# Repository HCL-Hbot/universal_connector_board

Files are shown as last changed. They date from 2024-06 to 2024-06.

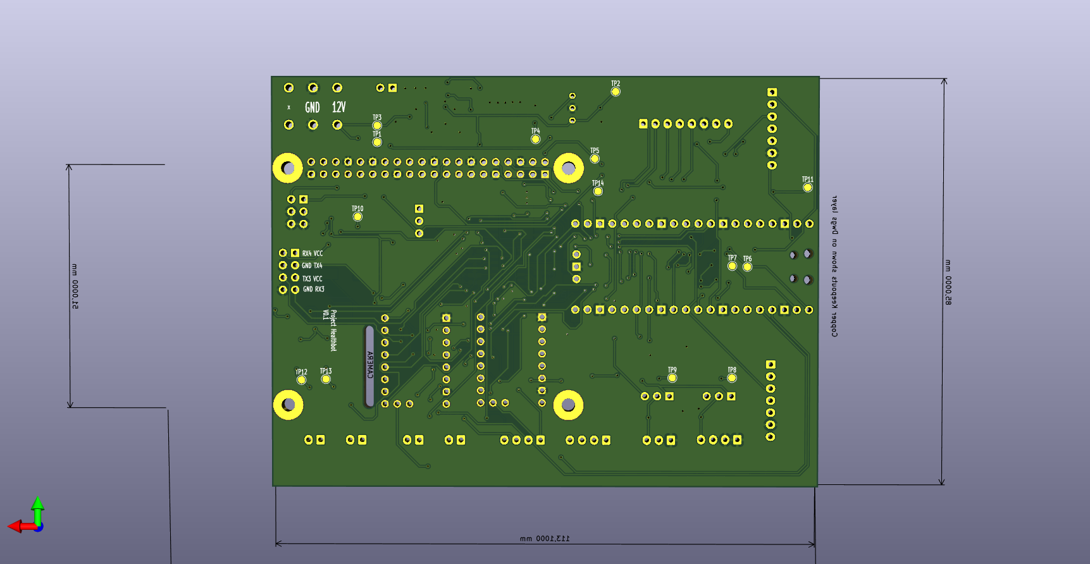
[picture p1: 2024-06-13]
Media/Back_3D.png

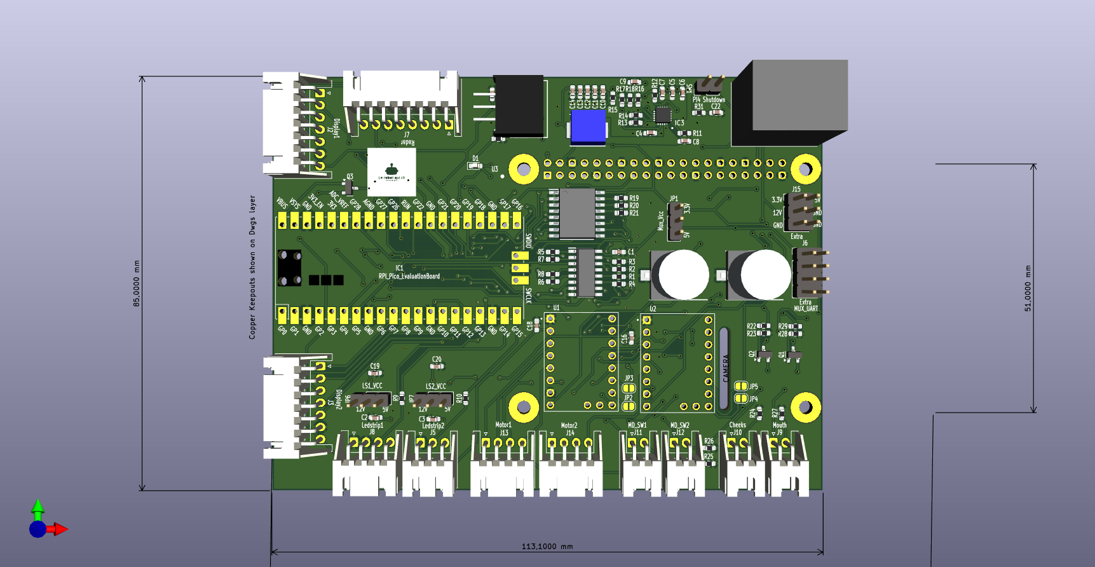
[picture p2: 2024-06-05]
Media/Front_3D.png

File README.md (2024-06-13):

# Healthboth PCB Design
This document outlines the contribution to a PCB design for project Healthbot, which is part of the Health Concept Lab of HAN University of Applied Sciences. It is part of a semester 6 student project including 3 Embedded Systems Engineers and 4 Industrial Design Engineers. The goal for this project was developing a social robot for healthcare, with several functionalities. This PCB is made to be integrated in the robot, but also made quite universal, so it can be used in new robot designs. In the folder media, there are images of the PCB. Because this was a first version, please look at the recommendations below!

## Components
Some components on the PCB that were needed are the I/O Expander, voltage regulators and an UART multiplexer. 
  ### I/O Expander
  Because the GPIO pins of the Pico were completely full and we still needed some, we added an I/O Expander which works with I2C. This expander has 8 I/O channels,   which are also all connected. 
  ### Voltage regulators
  Because of the several needed voltages for the components, two regulators are on the PCB. There is 12 Volt coming in to the PCB via the block terminal. This is     guided to a TSR 1-2433, which converts it to 3.3V. Also a 5V regulator is on the PCB, which was more complicated because it has to have a high output current due   to the ledstrips needing lots of current. 
  ### UART Multiplexer
  The motor driver modules can be controlled via UART communication. Because the Pico doesn't have lots of UART channels, and are already needed for                  communication between the RPI4 and the Pico e.g., an UART Multiplexer was added. Although we don't use it to control our motor drivers, this is still a      possibility because of this multiplexer. This also provided the board with 2 extra UART possibilities for whatever component needs it. 

## !! Issues 
1) The 5V regulator did not work. It is not clear if the regulator wasn't solderded correctly, or the buck converter circuit was not working. Anyways, there was a short between GND and 12V somewhere around the regulator. 
2) Each display needs a identical reset line. The reset line is apparently used to to sync, or atleast stabilize, even though there are seperate chip select lines. 
3) We do not know if the UART multiplexer works, because we don't use it and we needed a pin from the Pico to resolve the previous issue (see Temporary solutions below).

### Temporary solutions
1) Because of safety and time shortage, we just left out the 5V regulator and its circuit that did not work. We now provide 5V via the extra Vcc pins that were added originally as voltage output pins.
2) We used the Pico GPIO pin 21 as extra reset line for the 2nd display. This was originally the 'INH' of the UART Multiplexer. See image below for the connection made. Here can be seen that the trace on the PCB from GPIO21 to the UART Mux was deliberately damaged and replaced with a connection to the reset pin of the 2nd display.

Afbeelding van WhatsApp op 2024-06-13 om 12 24 14_29f4cc0a

## Recommendations
Below are recommendations for the next group that gets to design a PCB for project Healthbot. These are additions to the previous named issues that need to be adjusted. These recommendations are up to the next developer to decide.

1) Add explicit header pins next to the PICO. This can be useful to easily attach external equipment like a Logic Analyzer or TTL-module, or simply wires to a breadboard if needed. (You can see in the picture of the PCB that we soldered them on for now).
2) Flip the display pin order. This is convenient for testing and prototyping, because the displays can than just be connected (temporarily) to headers on the PCB without the need for several cables. 
3) Add more silk layer documenation. Some of this was already actually done in the design, but some of these labels were skipped during production for some reason. (Also adding small hints for Vcc, gnd and other pins could be useful for connecting the components, when not using JST connectors).
4) Add a working 5V regulator, with enough output current (>6A). Try to not use a regulator that is too small, this was a problem in the first version. 
5) Add status LEDs and just an onboard LED to control.
6) Add a couple of buttons, like to reset the PICO for example. Also, power on/off buttons would be nice (could be tricky for the RPI, but would be useful).

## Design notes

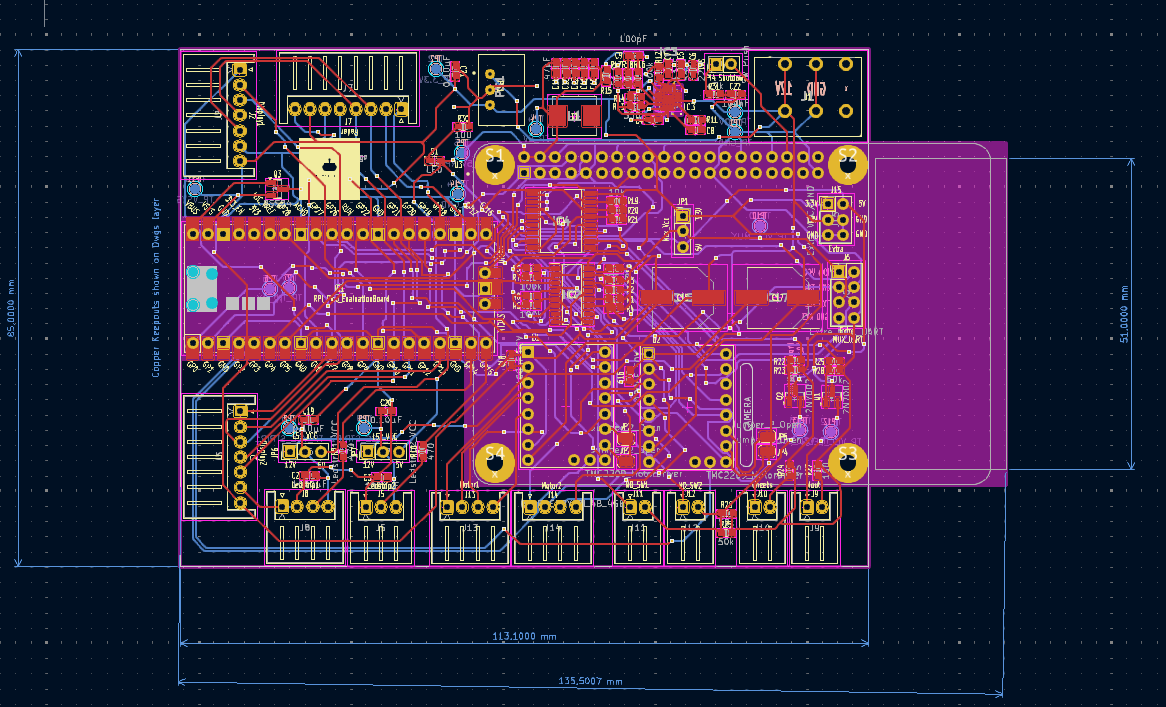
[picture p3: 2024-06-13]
Media/KiCad_PCB_Editor.png

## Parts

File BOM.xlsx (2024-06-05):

Reference, | Value | , | Datasheet | , | Footprint | , | Qty | , | DNP | , | Beschrijving
C1,C19,C20,C21, | 0.10Î¼F | , | ~ | , | Capacitor_SMD:C_0603_1608Metric_Pad1.08x0.95mm_HandSolder | , | 4 | , |  | ,
C2,C3, | 1000Î¼F | , | ~ | , | Capacitor_SMD:C_0603_1608Metric_Pad1.08x0.95mm_HandSolder | , | 2 | , |  | ,
C4, | 1uF | , | ~ | , | Capacitor_SMD:C_0603_1608Metric_Pad1.08x0.95mm_HandSolder | , | 1 | , |  | ,
C5,C6, | 22uF | , | ~ | , | Capacitor_SMD:C_0603_1608Metric_Pad1.08x0.95mm_HandSolder | , | 2 | , |  | ,
C7,C8,C10, | 0.1uF | , | ~ | , | Capacitor_SMD:C_0603_1608Metric_Pad1.08x0.95mm_HandSolder | , | 3 | , |  | ,
C9, | 100pF | , | ~ | , | Capacitor_SMD:C_0603_1608Metric_Pad1.08x0.95mm_HandSolder | , | 1 | , |  | ,
C11,C12,C13,C14, | 47ÂµF | , | ~ | , | Capacitor_SMD:C_0603_1608Metric_Pad1.08x0.95mm_HandSolder | , | 4 | , |  | ,
C15,C17, | Elec_Capacitor | , | https://www.vishay.com/docs/28403/146cti.pdf | , | SamacSys_Parts:CAPAE1000X1050N | , | 2 | , |  | , | Vishay Extreme 100uF 50 V Aluminium Electrolytic Capacitor 1010, 146 CTI Series 1000 h, 1500 h, 150000 h
C16,C18, | 100nF 50V | , | ~ | , | Capacitor_SMD:C_0603_1608Metric_Pad1.08x0.95mm_HandSolder | , | 2 | , |  | ,
C22, | 100nF | , | ~ | , | Capacitor_SMD:C_0603_1608Metric_Pad1.08x0.95mm_HandSolder | , | 1 | , |  | , | Unpolarized capacitor
D1, | LED | , | ~ | , | LED_SMD:LED_0603_1608Metric_Pad1.05x0.95mm_HandSolder | , | 1 | , |  | ,
IC1, | RPI_Pico_EvaluationBoard | , | https://datasheets.raspberrypi.com/pico/pico-datasheet.pdf | , | Healthbot-Footprints:RPi_Pico_SMD_TH | , | 1 | , |  | , | Raspberry Pi Pico W board
IC2, | SN74LV4052ADR | , | http://www.ti.com/lit/gpn/sn74lv4052a | , | Healthbot-Footprints:SOIC127P600X175-16N | , | 1 | , |  | ,
IC3, | TPS51397ARJER | , | https://www.ti.com/lit/gpn/tps51397a?HQS=ti-null-null-sf-df-pf-sep-wwe&DCM=yes | , | Healthbot-Footprints:QFN45P300X300X100-21N-D | , | 1 | , |  | ,
IC4, | TCA9534DWR | , | http://www.ti.com/lit/gpn/tca9534 | , | SamacSys_Parts:SOIC127P1030X265-16N | , | 1 | , |  | ,
J1, | 691401700003B | , | http://katalog.we-online.de/em/datasheet/6914017000xxB.pdf | , | SamacSys_Parts:691401700003B | , | 1 | , |  | , | Wurth Elektronik, 401B 5mm Pitch, 3 Way PCB Terminal Block
J2, | Display1 | , | ~ | , | Connector_JST:JST_XH_S7B-XH-A_1x07_P2.50mm_Horizontal | , | 1 | , |  | ,
J3, | Display2 | , | ~ | , | Connector_JST:JST_XH_S7B-XH-A_1x07_P2.50mm_Horizontal | , | 1 | , |  | ,
J5, | Ledstrip2 | , | ~ | , | Connector_JST:JST_XH_S3B-XH-A_1x03_P2.50mm_Horizontal | , | 1 | , |  | ,
J6, | Extra MUX_UART | , | ~ | , | Connector_PinHeader_2.54mm:PinHeader_2x04_P2.54mm_Vertical | , | 1 | , |  | ,
J7, | Radar | , | ~ | , | Connector_JST:JST_XH_S8B-XH-A_1x08_P2.50mm_Horizontal | , | 1 | , |  | , | Generic connector, single row, 01x08, script generated
J8, | Ledstrip1 | , | ~ | , | Connector_JST:JST_XH_S4B-XH-A_1x04_P2.50mm_Horizontal | , | 1 | , |  | ,
J9, | Mouth | , | ~ | , | Connector_JST:JST_XH_S2B-XH-A_1x02_P2.50mm_Horizontal | , | 1 | , |  | ,
J10, | Cheeks | , | ~ | , | Connector_JST:JST_XH_S2B-XH-A_1x02_P2.50mm_Horizontal | , | 1 | , |  | ,
J11, | MD_SW1 | , | ~ | , | Connector_JST:JST_XH_S2B-XH-A_1x02_P2.50mm_Horizontal | , | 1 | , |  | ,
J12, | MD_SW2 | , | ~ | , | Connector_JST:JST_XH_S2B-XH-A_1x02_P2.50mm_Horizontal | , | 1 | , |  | ,
J13, | Motor1 | , | ~ | , | Connector_JST:JST_XH_S4B-XH-A_1x04_P2.50mm_Horizontal | , | 1 | , |  | ,
J14, | Motor2 | , | ~ | , | Connector_JST:JST_XH_S4B-XH-A_1x04_P2.50mm_Horizontal | , | 1 | , |  | ,
J15, | Extra VCC/GND | , | ~ | , | Connector_PinHeader_2.54mm:PinHeader_2x03_P2.54mm_Vertical | , | 1 | , |  | ,
JP1, | Mux_Vcc | , | ~ | , | Connector_PinHeader_2.54mm:PinHeader_1x03_P2.54mm_Vertical | , | 1 | , |  | ,
JP2,JP3,JP4,JP5, | Jumper_2_Open | , | ~ | , | Jumper:SolderJumper-2_P1.3mm_Open_RoundedPad1.0x1.5mm | , | 4 | , |  | ,
JP6, | Ledstrip1_VCC | , | ~ | , | Connector_PinHeader_2.54mm:PinHeader_1x03_P2.54mm_Vertical | , | 1 | , |  | ,
JP7, | Ledstrip2_VCC | , | ~ | , | Connector_PinHeader_2.54mm:PinHeader_1x03_P2.54mm_Vertical | , | 1 | , |  | ,
L1, | SRP6540-1R0M | , | https://www.bourns.com/docs/Product-Datasheets/SRP6540.pdf | , | Healthbot-Footprints:INDPM7265X400N | , | 1 | , |  | , | Bourns SRP6540 Series Shielded Wire-wound SMD Inductor with a Iron Core, 1 uH +/-20% Wire-Wound 12A Idc
PS1, | TSR_1-2433 | , | https://tracopower.com/tsr1-datasheet/ | , | Healthbot-Footprints:TSR-1-2433 | , | 1 | , |  | , | 1 Amp POL switching regulator, 4.6 to -36 VDC input, pos.-pos. circuit, LM78 compatible, SIP-3
Q1,Q2, | 2N7002 | , | https://www.onsemi.com/pub/Collateral/NDS7002A-D.PDF | , | Package_TO_SOT_SMD:SOT-23 | , | 2 | , |  | , | 0.115A Id, 60V Vds, N-Channel MOSFET, SOT-23
Q3, | BSS84 | , | http://assets.nexperia.com/documents/data-sheet/BSS84.pdf | , | Package_TO_SOT_SMD:SOT-23 | , | 1 | , |  | , | -0.13A Id, -50V Vds, P-Channel MOSFET, SOT-23
R1,R2,R3,R4,R5,R6,R7,R8,R12, | 100k | , | ~ | , | Resistor_SMD:R_0603_1608Metric_Pad0.98x0.95mm_HandSolder | , | 9 | , |  | ,
R9,R10, | 470 | , | ~ | , | Resistor_SMD:R_0603_1608Metric_Pad0.98x0.95mm_HandSolder | , | 2 | , |  | ,
R11,R18, | 0 | , | ~ | , | Resistor_SMD:R_0603_1608Metric_Pad0.98x0.95mm_HandSolder | , | 2 | , |  | ,
R13, | 330k | , | ~ | , | Resistor_SMD:R_0603_1608Metric_Pad0.98x0.95mm_HandSolder | , | 1 | , |  | ,
R14,R17, | 15k | , | ~ | , | Resistor_SMD:R_0603_1608Metric_Pad0.98x0.95mm_HandSolder | , | 2 | , |  | ,
R15, | 51.1 | , | ~ | , | Resistor_SMD:R_0603_1608Metric_Pad0.98x0.95mm_HandSolder | , | 1 | , |  | ,
R16, | 110k | , | ~ | , | Resistor_SMD:R_0603_1608Metric_Pad0.98x0.95mm_HandSolder | , | 1 | , |  | ,
R19,R20,R21, | 10k | , | ~ | , | Resistor_SMD:R_0603_1608Metric_Pad0.98x0.95mm_HandSolder | , | 3 | , |  | ,
R22,R29, | 47 | , | ~ | , | Resistor_SMD:R_0603_1608Metric_Pad0.98x0.95mm_HandSolder | , | 2 | , |  | ,
R23,R25,R26,R28, | 50k | , | ~ | , | Resistor_SMD:R_0603_1608Metric_Pad0.98x0.95mm_HandSolder | , | 4 | , |  | ,
R24, | 75 | , | ~ | , | Resistor_SMD:R_0603_1608Metric_Pad0.98x0.95mm_HandSolder | , | 1 | , |  | ,
R27,R30, | 100 | , | ~ | , | Resistor_SMD:R_0603_1608Metric_Pad0.98x0.95mm_HandSolder | , | 2 | , |  | ,
R31, | 4.7k | , | ~ | , | Resistor_SMD:R_0603_1608Metric_Pad0.98x0.95mm_HandSolder | , | 1 | , |  | , | Resistor
SW1, | SW_Push | , | ~ | , | Connector_PinHeader_2.54mm:PinHeader_1x02_P2.54mm_Vertical | , | 1 | , |  | ,
TP2, | TP_3.3V | , | ~ | , | TestPoint:TestPoint_Pad_D1.5mm | , | 1 | , |  | , | test point
TP3, | TP_12V | , | ~ | , | TestPoint:TestPoint_Pad_D1.5mm | , | 1 | , |  | , | test point
TP4, | TP_5V | , | ~ | , | TestPoint:TestPoint_Pad_D1.5mm | , | 1 | , |  | , | test point
TP5,TP14, | TP_GND | , | ~ | , | TestPoint:TestPoint_Pad_D1.5mm | , | 2 | , |  | , | test point
TP6, | TP_RX | , | ~ | , | TestPoint:TestPoint_Pad_D1.5mm | , | 1 | , |  | , | test point
TP7, | TP_TX | , | ~ | , | TestPoint:TestPoint_Pad_D1.5mm | , | 1 | , |  | , | test point
TP8, | TP_VCC_STRIP1 | , | ~ | , | TestPoint:TestPoint_Pad_D1.5mm | , | 1 | , |  | , | test point
TP9, | TP_VCC_STRIP2 | , | ~ | , | TestPoint:TestPoint_Pad_D1.5mm | , | 1 | , |  | , | test point
TP10, | TP_VCC_MUX | , | ~ | , | TestPoint:TestPoint_Pad_D1.5mm | , | 1 | , |  | , | test point
TP11, | TP_VSYS | , | ~ | , | TestPoint:TestPoint_Pad_D1.5mm | , | 1 | , |  | , | test point
TP12, | TP_VCC_LEDM | , | ~ | , | TestPoint:TestPoint_Pad_D1.5mm | , | 1 | , |  | , | test point
TP13, | TP_VCC_LEDC | , | ~ | , | TestPoint:TestPoint_Pad_D1.5mm | , | 1 | , |  | , | test point
TP15, | TP_5V_RPI4 | , | ~ | , | TestPoint:TestPoint_Pad_D1.5mm | , | 1 | , |  | , | test point
U1,U2, | TMC2209_MotorDriver | , | https://www.analog.com/media/en/technical-documentation/data-sheets/TMC2209_datasheet_rev1.09.pdf | , | Healthbot-Footprints:MODULE_TMC2209_SILENTSTEPSTICK | , | 2 | , |  | , | TMC2209 Motor Controller/Driver Power Management Evaluation Board
U3, | RASPBERRY_PI_4B_4GB | , |  | , | Healthbot-Footprints:MODULE_RASPBERRY_PI_4B_4GB | , | 1 | , |  | ,

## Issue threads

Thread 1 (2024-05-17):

Review schematic

MarelleV, 2024-05-17:
Could one or both take a look at the schematic? I mentioned some things in the 'notes' sections, please take a look at that.

Hoog-V, 2024-05-17:
Hi Marelle, I have looked at your schematic. I added some missing connections and turned the GND symbols to the downward position. I have a tip when choosing your inductor; Look at the saturation current and not the max current rating. As the saturation current is the current at which your inductor starts losing inductance. So when designing for 5V 10A choose a inductor >12A saturation current.

Another thing that I stumbled up on are the pins reserved for the radar but not connected to anything, pin headers e.g.

Oh and have you tried checking the schematic using the [built-in erc checker](https://docs.kicad.org/master/en/getting_started_in_kicad/getting_started_in_kicad.html#electrical_rules_check) ?

Hoog-V, 2024-05-17:
BTW; Wow! Good Job, I liked how structured your schematic is! It is better then the schematics I make! For the first PCB ever? I am proud of you!

Have a good weekend,

Victor

MarelleV, 2024-05-18:
Thanks @Hoog-V ! I'll take a look at the things you mentioned. I appreciate the tip, sometimes I forget which data is most important for which component 😅 I'll try the built-in erc checker, i have not done that yet

RichardKroesen, 2024-05-20:
Looks good and well organized. I like the Excel sheet ;)
Here a couple of points of attention from me (the decision of what do to do with it is up to you):

But first off all just so you know, we cannot check all the details of the schematic. I just look quickly and check whether it makes sense, and go to the datasheet to check when in doubt.

1. I would not recommend making the power inputs as a hierarchical label, because it is confusion.
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
But I see why you did it. You can just use the global +12V inside the hierarchical sheet itself.
Btw, for regulators from a input source it does make sense so here I would do this as well. But maybe not call it 12V. Because are we for sure it is a clean 12V source?
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
2. Place the power labels, please upright (yeah details haha)
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
And because I'm already picky, also place the grounds always downwards:P.

 3. Just split this circuit, maybe you wanted to keep them together but it is not really at first look.

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
4. This is just a WIP err but just to note it:
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
5. Make a custom footprint component of this.
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
For me this is a MUST to do, because if someone wants to reuse it, it should be well defined as a footprint.

6. In the notes you mentioned about the layout and routing, here is what I think is a good idea in big lines:
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
But again, I was just playing around so I didn't carefully looked at where for example the wifi IC of RPI4 is located which might be disturbed now.
In general I would do this:
- Layout in big lines your components, and start thinking in sections as I did above.
- Start implementing your circuits, for example the regulators and finish them. Keep them appart from the rest!
- Finish other sections.
- Start integrating and fine-tuning.
- Place inputs and outputs together.
- Place additional text labels for easier connectivity later.
7. Can you add just in case a HW bouncing elements here
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
8. Radar connector: I mis him :( haha yeah it is not properly implemented but will be some day XD
All in all a well looking schematic already,

Closed 2024-06-08.

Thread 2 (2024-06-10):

PATCH: Board Patches HBOT-UniversalBoard-REV1-P1

RichardKroesen, 2024-06-10:
## Notice
First of, just to be explicit this issue is not meant as a critics post or with a negative intent. The purpose is to document the patches I did to make the current design operational, and which should and could be easily fixed in the next PCB revision.

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

## Issues List
- [ ] DC-DC Stepdown, implementated with a buck converter: not yet sure if this is a design think, or we did not solder properly the IC (looked fine, check picture nr.1) but there was a short between GND and 12V (hard-one) somewhere in this section. I tried to troubleshoot step-by-step, but to be honest I stopped after a while because I did not want to bother furture and just test the FW instead.
- [ ] Display pin order must be flipped, for testing and prototyping it is just nicer to have them the other way. It was properly just not checked, and it is not an issues for deployment itself.
- [ ] EACH display needs a identical reset line, the reset line is apparently used to to sync or atleast stabilize (not sure about the details) even though there are seperate chip select lines.
- [ ] We did not yet test the UART MUX.

## Patches List as a Temporary Solution
- PicoPin 21 (GPIO16), MUX_INH -to-> **2nd display reset line.**
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
- Added external adapters as work-around power regulation.

## Good Things
I don't like to be negative, so I cannot resist to mention some positive things here!
- Extra PSU Header: This one really saved the whole PCB and a lot of troubles, because you can just connect here your external adapters and use the board just like you would with a functional power regulation.
- No problems were found with the IO Expander :)
- The cut-out for the Camera has good margins.
- The jumpers for the LEDSTRIPS are so awesome, you can just connect both 5 and 12V WS28XX ledstrip!
- There were good Testpoints placed which were convenient during trouble-shooting and measurements :D

## Recommendations
For the next group:
1. Add explicit header pins besides the PICO, I found it extremely convenient to just add male rows for external equipment. Like Logic Analyzer, TTL-module or just jumpers to my breadboard. I think this is so benefitial for other students as well.
2. Add more silk layer documenation, tbh this some header labels where not skipped during production for some reason (Produced in China....)
3. Please when designing power regulation know what you are doing. When you have not yet experience but have time create a breadboard circuit, evaluationkit or a perf-board with the IC you want to use. Secondly, please plainly copy the layout what the datasheet recommends  and don't try to innovate here, the manufacture already did the work.
4. Add status LEDs and just a onboard LED to control.
5. Add a couple of buttons, like to reset the PICO for example.
6. Add Power down and powerup(a bit trickyer for the RPI but a nice challenge ;) )
7. Please make sure the BOM (Bill-of-Materials) is always right with the HW the corresponding revision or order. Sure generic parts could be obtained somewhere, but come on they aint gona make a financial different and it is just painful to obtain them last-minute by searching and asking around. So just order them or spend more money by wasting time (sorry, I had to faint my frustration somewhere ;D)

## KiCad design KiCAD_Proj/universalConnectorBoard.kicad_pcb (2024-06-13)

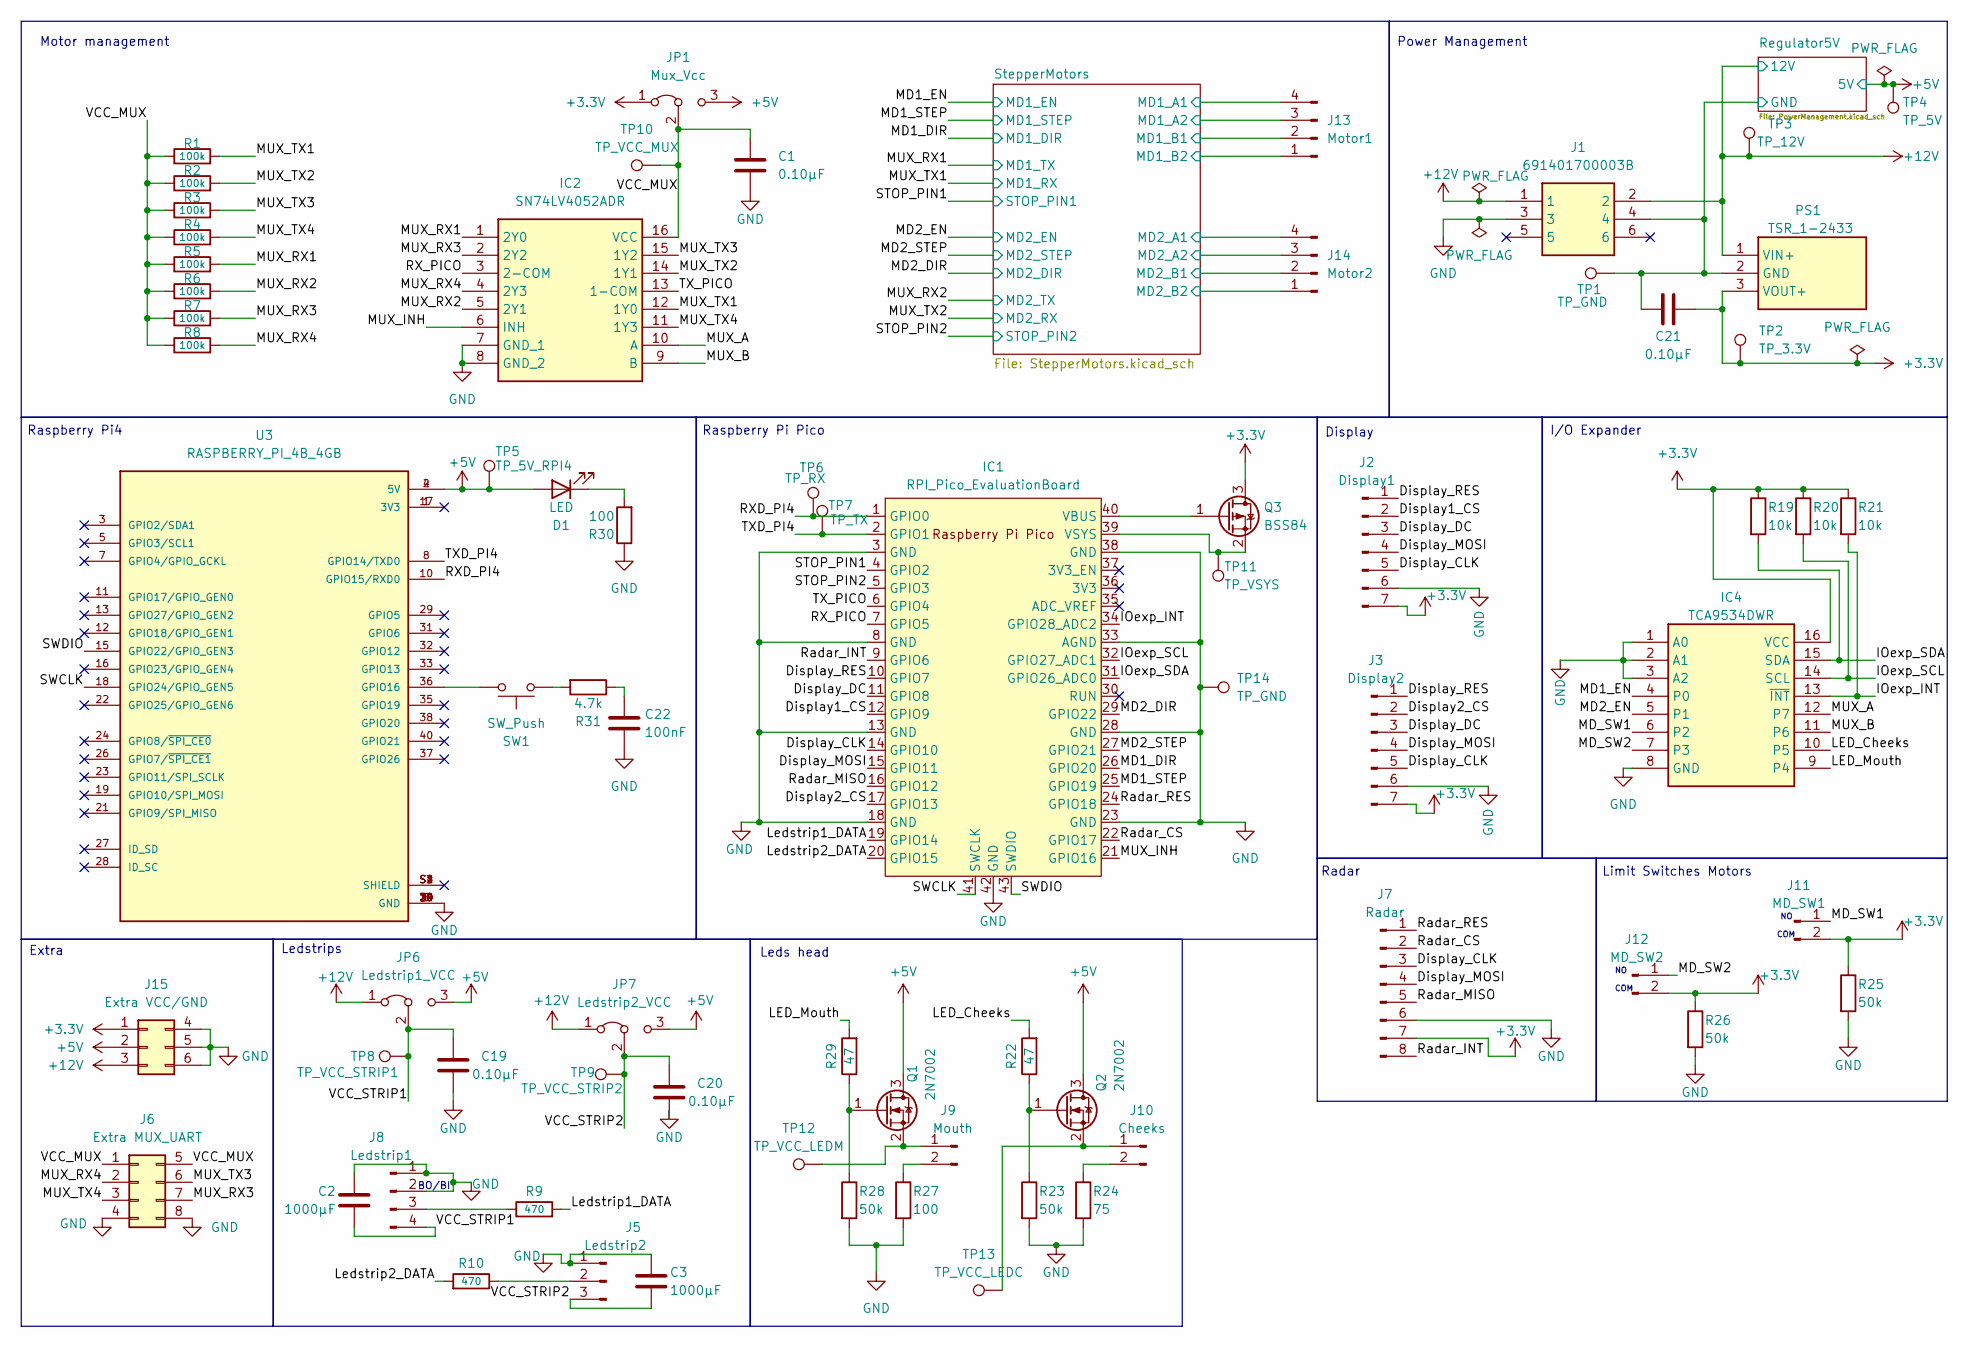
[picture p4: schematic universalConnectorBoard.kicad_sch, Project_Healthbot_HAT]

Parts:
C1, C19, C20, C21: 0.10μF; C_0603_1608Metric_Pad1.08x0.95mm_HandSolder
C2, C3: 1000μF; C_0603_1608Metric_Pad1.08x0.95mm_HandSolder
C22: 100nF; C_0603_1608Metric_Pad1.08x0.95mm_HandSolder
D1: LED; LED_0603_1608Metric_Pad1.05x0.95mm_HandSolder
IC1: RPI_Pico_EvaluationBoard; RPi_Pico_SMD_TH
IC2: SN74LV4052ADR; SOIC127P600X175-16N; Mouser Part Number 595-SN74LV4052ADR
IC4: TCA9534DWR; SOIC127P1030X265-16N; Mouser Part Number 595-TCA9534DWR
J1: 691401700003B; Manufacturer_Part_Number 691401700003B
J2: Display1; JST_XH_S7B-XH-A_1x07_P2.50mm_Horizontal
J3: Display2; JST_XH_S7B-XH-A_1x07_P2.50mm_Horizontal
J5: Ledstrip2; JST_XH_S3B-XH-A_1x03_P2.50mm_Horizontal
J6: Extra MUX_UART; PinHeader_2x04_P2.54mm_Vertical
J7: Radar; JST_XH_S8B-XH-A_1x08_P2.50mm_Horizontal
J8: Ledstrip1; JST_XH_S4B-XH-A_1x04_P2.50mm_Horizontal
J9: Mouth; JST_XH_S2B-XH-A_1x02_P2.50mm_Horizontal
J10: Cheeks; JST_XH_S2B-XH-A_1x02_P2.50mm_Horizontal
J11: MD_SW1; JST_XH_S2B-XH-A_1x02_P2.50mm_Horizontal
J12: MD_SW2; JST_XH_S2B-XH-A_1x02_P2.50mm_Horizontal
J13: Motor1; JST_XH_S4B-XH-A_1x04_P2.50mm_Horizontal
J14: Motor2; JST_XH_S4B-XH-A_1x04_P2.50mm_Horizontal
J15: Extra VCC/GND; PinHeader_2x03_P2.54mm_Vertical
JP1: Mux_Vcc; PinHeader_1x03_P2.54mm_Vertical
JP6: Ledstrip1_VCC; PinHeader_1x03_P2.54mm_Vertical
JP7: Ledstrip2_VCC; PinHeader_1x03_P2.54mm_Vertical
PS1: TSR_1-2433; TSR-1-2433; Manufacturer_Part_Number TSR 1-2433
Q1, Q2: 2N7002; SOT-23
Q3: BSS84; SOT-23
R1, R2, R3, R4, R5, R6, R7, R8: 100k; R_0603_1608Metric_Pad0.98x0.95mm_HandSolder
R9, R10: 470; R_0603_1608Metric_Pad0.98x0.95mm_HandSolder
R19, R20, R21: 10k; R_0603_1608Metric_Pad0.98x0.95mm_HandSolder
R22, R29: 47; R_0603_1608Metric_Pad0.98x0.95mm_HandSolder
R23, R25, R26, R28: 50k; R_0603_1608Metric_Pad0.98x0.95mm_HandSolder
R24: 75; R_0603_1608Metric_Pad0.98x0.95mm_HandSolder
R27, R30: 100; R_0603_1608Metric_Pad0.98x0.95mm_HandSolder
R31: 4.7k; R_0603_1608Metric_Pad0.98x0.95mm_HandSolder
SW1: SW_Push; PinHeader_1x02_P2.54mm_Vertical
TP1, TP14: TP_GND; TestPoint_Pad_D1.5mm
TP2: TP_3.3V; TestPoint_Pad_D1.5mm
TP3: TP_12V; TestPoint_Pad_D1.5mm
TP4: TP_5V; TestPoint_Pad_D1.5mm
TP5: TP_5V_RPI4; TestPoint_Pad_D1.5mm
TP6: TP_RX; TestPoint_Pad_D1.5mm
TP7: TP_TX; TestPoint_Pad_D1.5mm
TP8: TP_VCC_STRIP1; TestPoint_Pad_D1.5mm
TP9: TP_VCC_STRIP2; TestPoint_Pad_D1.5mm
TP10: TP_VCC_MUX; TestPoint_Pad_D1.5mm
TP11: TP_VSYS; TestPoint_Pad_D1.5mm
TP12: TP_VCC_LEDM; TestPoint_Pad_D1.5mm
TP13: TP_VCC_LEDC; TestPoint_Pad_D1.5mm
U3: RASPBERRY_PI_4B_4GB; MODULE_RASPBERRY_PI_4B_4GB; PARTREV 4

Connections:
+3.3V: C21.2, IC4.16 (VCC), J2.7, J3.7, J7.7, J11.2, J12.2, J15.1, JP1.1 (A), PS1.3 (VOUT+), Q3.3 (D), R19.1, R20.1, R21.1, R25.1, R26.1, TP2.1; also elsewhere on the board
+5V: D1.2 (A), J15.2, JP1.3 (B), JP6.3 (B), JP7.3 (B), Q1.3 (D), Q2.3 (D), TP4.1, TP5.1, U3.2 (5V), U3.4 (5V); also elsewhere on the board
+12V: J1.1, J1.2, J15.3, JP6.1 (A), JP7.1 (A), PS1.1 (VIN+), TP3.1; also elsewhere on the board
/Display1_CS: IC1.12 (GPIO9), J2.2
/Display2_CS: IC1.17 (GPIO13), J3.2
/Display_CLK: IC1.14 (GPIO10), J2.5, J3.5, J7.3
/Display_DC: IC1.11 (GPIO8), J2.3, J3.3
/Display_MOSI: IC1.15 (GPIO11), J2.4, J3.4, J7.4
/Display_RES: IC1.10 (GPIO7), J2.1, J3.1
/IOexp_INT: IC1.34 (GPIO28_ADC2), IC4.13 (~INT), R21.2
/IOexp_SCL: IC1.32 (GPIO27_ADC1), IC4.14 (SCL), R20.2
/IOexp_SDA: IC1.31 (GPIO26_ADC0), IC4.15 (SDA), R19.2
/LED_Cheeks: IC4.10 (P5), R22.2
/LED_Mouth: IC4.9 (P4), R29.2
/Ledstrip1_DATA: IC1.19 (GPIO14), R9.2
/Ledstrip2_DATA: IC1.20 (GPIO15), R10.2
/MD1_DIR: IC1.26 (GPIO20); also elsewhere on the board
/MD1_EN: IC4.4 (P0); also elsewhere on the board
/MD1_STEP: IC1.25 (GPIO19); also elsewhere on the board
/MD2_DIR: IC1.29 (GPIO22); also elsewhere on the board
/MD2_EN: IC4.5 (P1); also elsewhere on the board
/MD2_STEP: IC1.27 (GPIO21); also elsewhere on the board
/MD_SW1: IC4.6 (P2), J11.1
/MD_SW2: IC4.7 (P3), J12.1
/MUX_A: IC2.10 (A), IC4.12 (P7)
/MUX_B: IC2.9 (B), IC4.11 (P6)
/MUX_INH: IC1.21 (GPIO16), IC2.6 (INH)
/MUX_RX1: IC2.1 (2Y0), R5.2; also elsewhere on the board
/MUX_RX2: IC2.5 (2Y1), R6.2; also elsewhere on the board
/MUX_RX3: IC2.2 (2Y2), J6.7, R7.2
/MUX_RX4: IC2.4 (2Y3), J6.2, R8.2
/MUX_TX1: IC2.12 (1Y0), R1.2; also elsewhere on the board
/MUX_TX2: IC2.14 (1Y1), R2.2; also elsewhere on the board
/MUX_TX3: IC2.15 (1Y2), J6.6, R3.2
/MUX_TX4: IC2.11 (1Y3), J6.3, R4.2
/RXD_PI4: IC1.1 (GPIO0), TP6.1, U3.10 (GPIO15/RXD0)
/RX_PICO: IC1.7 (GPIO5), IC2.3 (2-COM)
/Radar_CS: IC1.22 (GPIO17), J7.2
/Radar_INT: IC1.9 (GPIO6), J7.8
/Radar_MISO: IC1.16 (GPIO12), J7.5
/Radar_RES: IC1.24 (GPIO18), J7.1
/STOP_PIN1: IC1.4 (GPIO2); also elsewhere on the board
/STOP_PIN2: IC1.5 (GPIO3); also elsewhere on the board
/SWCLK: IC1.41 (SWCLK), U3.18 (GPIO24/GPIO_GEN5)
/SWDIO: IC1.43 (SWDIO), U3.15 (GPIO22/GPIO_GEN3)
/StepperMotors/MD1_A1: J13.4; also elsewhere on the board
/StepperMotors/MD1_A2: J13.3; also elsewhere on the board
/StepperMotors/MD1_B1: J13.2; also elsewhere on the board
/StepperMotors/MD1_B2: J13.1; also elsewhere on the board
/StepperMotors/MD2_A1: J14.4; also elsewhere on the board
/StepperMotors/MD2_A2: J14.3; also elsewhere on the board
/StepperMotors/MD2_B1: J14.2; also elsewhere on the board
/StepperMotors/MD2_B2: J14.1; also elsewhere on the board
/TXD_PI4: IC1.2 (GPIO1), TP7.1, U3.8 (GPIO14/TXD0)
/TX_PICO: IC1.6 (GPIO4), IC2.13 (1-COM)
/VCC_MUX: C1.1, IC2.16 (VCC), J6.1, J6.5, JP1.2 (C), R1.1, R2.1, R3.1, R4.1, R5.1, R6.1, R7.1, R8.1, TP10.1
/VCC_STRIP1: C2.2, C19.1, J8.4, JP6.2 (C), TP8.1
/VCC_STRIP2: C3.2, C20.1, J5.3, JP7.2 (C), TP9.1
GND: C1.2, C2.1, C3.1, C19.2, C20.2, C21.1, C22.2, IC1.3 (GND), IC1.8 (GND), IC1.13 (GND), IC1.18 (GND), IC1.23 (GND), IC1.28 (GND), IC1.33 (AGND), IC1.38 (GND), IC1.42 (GND), IC2.7 (GND_1), IC2.8 (GND_2), IC4.1 (A0), IC4.2 (A1), IC4.3 (A2), IC4.8 (GND), J1.3, J1.4, J2.6, J3.6, J5.1, J6.4, J6.8, J7.6, J8.1, J8.2, J15.4, J15.5, J15.6, PS1.2 (GND), R23.2, R24.2, R25.2, R26.2, R27.2, R28.2, R30.1, TP1.1, TP14.1, U3.6 (GND), U3.9 (GND), U3.14 (GND), U3.20 (GND), U3.25 (GND), U3.30 (GND), U3.34 (GND), U3.39 (GND); also elsewhere on the board
unnamed: C22.1, R31.1
unnamed: D1.1 (K), R30.2
unnamed: IC1.40 (VBUS), Q3.1 (G)
unnamed: IC1.39 (VSYS), Q3.2 (S), TP11.1
unnamed: J5.2, R10.1
unnamed: J8.3, R9.1
unnamed: J9.1, Q1.2 (S), TP12.1
unnamed: J9.2, R27.1
unnamed: J10.1, Q2.2 (S), TP13.1
unnamed: J10.2, R24.1
unnamed: Q1.1 (G), R28.1, R29.1
unnamed: Q2.1 (G), R22.1, R23.1
unnamed: R31.2, SW1.1
unnamed: SW1.2, U3.36 (GPIO16)

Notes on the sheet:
Display
Motor management
Raspberry Pi Pico
Power Management
BO/BI
Limit Switches Motors
COM
Raspberry Pi4
Ledstrips
Leds head
Radar
I/O Expander
Extra

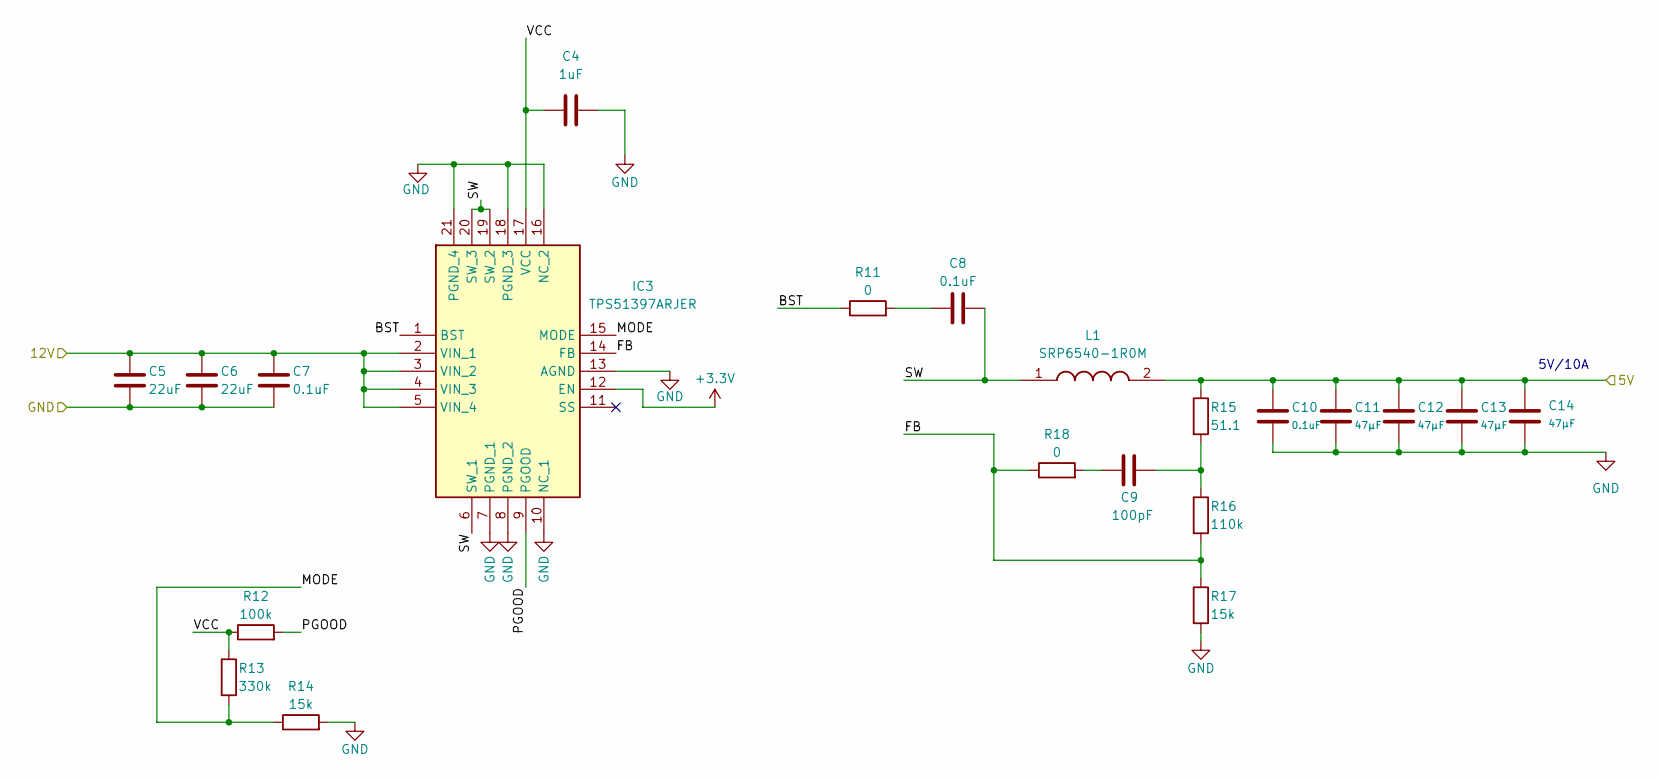
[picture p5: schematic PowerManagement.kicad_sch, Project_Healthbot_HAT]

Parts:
C4: 1uF; C_0603_1608Metric_Pad1.08x0.95mm_HandSolder
C5, C6: 22uF; C_0603_1608Metric_Pad1.08x0.95mm_HandSolder
C7, C8, C10: 0.1uF; C_0603_1608Metric_Pad1.08x0.95mm_HandSolder
C9: 100pF; C_0603_1608Metric_Pad1.08x0.95mm_HandSolder
C11, C12, C13, C14: 47µF; C_0603_1608Metric_Pad1.08x0.95mm_HandSolder
IC3: TPS51397ARJER; QFN45P300X300X100-21N-D; Mouser Part Number 595-TPS51397ARJER
L1: SRP6540-1R0M; INDPM7265X400N; Manufacturer_Part_Number SRP6540-1R0M
R11, R18: 0; R_0603_1608Metric_Pad0.98x0.95mm_HandSolder
R12: 100k; R_0603_1608Metric_Pad0.98x0.95mm_HandSolder
R13: 330k; R_0603_1608Metric_Pad0.98x0.95mm_HandSolder
R14, R17: 15k; R_0603_1608Metric_Pad0.98x0.95mm_HandSolder
R15: 51.1; R_0603_1608Metric_Pad0.98x0.95mm_HandSolder
R16: 110k; R_0603_1608Metric_Pad0.98x0.95mm_HandSolder

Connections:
+3.3V: IC3.12 (EN); also elsewhere on the board
+5V: C10.1, C11.1, C12.1, C13.1, C14.1, L1.2, R15.1; also elsewhere on the board
+12V: C5.1, C6.1, C7.1, IC3.2 (VIN_1), IC3.3 (VIN_2), IC3.4 (VIN_3), IC3.5 (VIN_4); also elsewhere on the board
/Regulator5V/BST: IC3.1 (BST), R11.1
/Regulator5V/FB: IC3.14 (FB), R16.2, R17.1, R18.1
/Regulator5V/MODE: IC3.15 (MODE), R13.2, R14.1
/Regulator5V/PGOOD: IC3.9 (PGOOD), R12.2
/Regulator5V/SW: C8.2, IC3.6 (SW_1), IC3.19 (SW_2), IC3.20 (SW_3), L1.1
/Regulator5V/VCC: C4.1, IC3.17 (VCC), R12.1, R13.1
GND: C4.2, C5.2, C6.2, C7.2, C10.2, C11.2, C12.2, C13.2, C14.2, IC3.7 (PGND_1), IC3.8 (PGND_2), IC3.10 (NC_1), IC3.13 (AGND), IC3.16 (NC_2), IC3.18 (PGND_3), IC3.21 (PGND_4), R14.2, R17.2; also elsewhere on the board
unnamed: C8.1, R11.2
unnamed: C9.1, R15.2, R16.1
unnamed: C9.2, R18.2

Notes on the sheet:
5V/10A

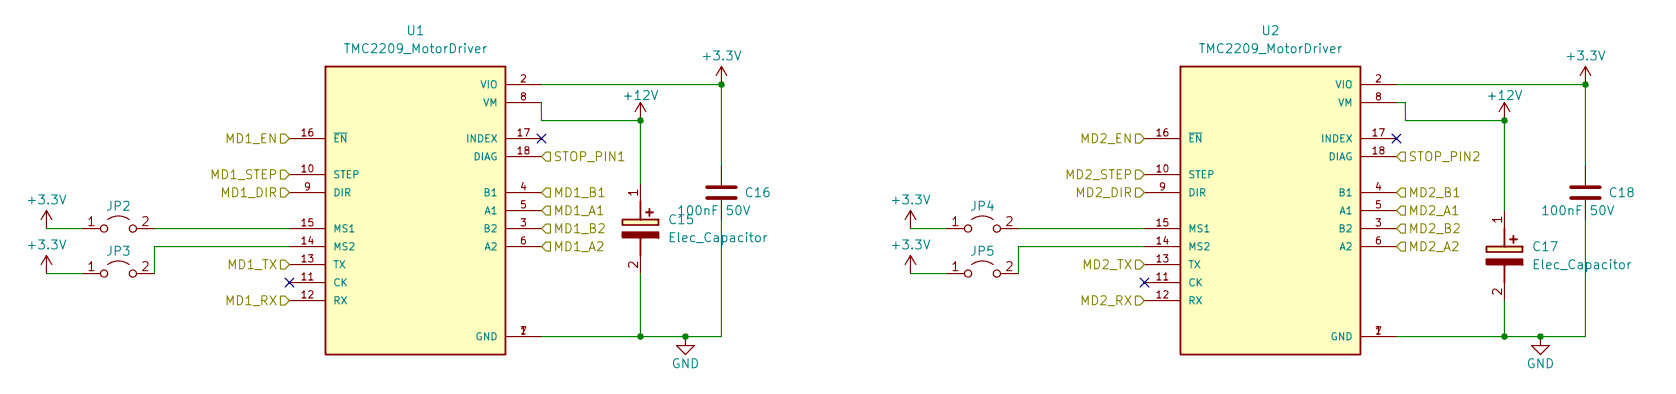
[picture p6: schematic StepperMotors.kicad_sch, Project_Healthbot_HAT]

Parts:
C15, C17: Elec_Capacitor; CAPAE1000X1050N; Mouser Part Number 594-MAL214699103E3
C16, C18: 100nF 50V; C_0603_1608Metric_Pad1.08x0.95mm_HandSolder; LCSC C476766
JP2, JP3, JP4, JP5: Jumper_2_Open; SolderJumper-2_P1.3mm_Open_RoundedPad1.0x1.5mm; LCSC x
U1, U2: TMC2209_MotorDriver; MODULE_TMC2209_SILENTSTEPSTICK; PARTREV 1.20

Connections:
+3.3V: C16.1, C18.1, JP2.1 (A), JP3.1 (A), JP4.1 (A), JP5.1 (A), U1.2 (VIO), U2.2 (VIO); also elsewhere on the board
+12V: C15.1 (+), C17.1 (+), U1.8 (VM), U2.8 (VM); also elsewhere on the board
/MD1_DIR: U1.9 (DIR); also elsewhere on the board
/MD1_EN: U1.16 (~EN); also elsewhere on the board
/MD1_STEP: U1.10 (STEP); also elsewhere on the board
/MD2_DIR: U2.9 (DIR); also elsewhere on the board
/MD2_EN: U2.16 (~EN); also elsewhere on the board
/MD2_STEP: U2.10 (STEP); also elsewhere on the board
/MUX_RX1: U1.13 (TX); also elsewhere on the board
/MUX_RX2: U2.13 (TX); also elsewhere on the board
/MUX_TX1: U1.12 (RX); also elsewhere on the board
/MUX_TX2: U2.12 (RX); also elsewhere on the board
/STOP_PIN1: U1.18 (DIAG); also elsewhere on the board
/STOP_PIN2: U2.18 (DIAG); also elsewhere on the board
/StepperMotors/MD1_A1: U1.5 (A1); also elsewhere on the board
/StepperMotors/MD1_A2: U1.6 (A2); also elsewhere on the board
/StepperMotors/MD1_B1: U1.4 (B1); also elsewhere on the board
/StepperMotors/MD1_B2: U1.3 (B2); also elsewhere on the board
/StepperMotors/MD2_A1: U2.5 (A1); also elsewhere on the board
/StepperMotors/MD2_A2: U2.6 (A2); also elsewhere on the board
/StepperMotors/MD2_B1: U2.4 (B1); also elsewhere on the board
/StepperMotors/MD2_B2: U2.3 (B2); also elsewhere on the board
GND: C15.2 (-), C16.2, C17.2 (-), C18.2, U1.1 (GND), U1.7 (GND), U2.1 (GND), U2.7 (GND); also elsewhere on the board
unnamed: JP2.2 (B), U1.15 (MS1)
unnamed: JP3.2 (B), U1.14 (MS2)
unnamed: JP4.2 (B), U2.15 (MS1)
unnamed: JP5.2 (B), U2.14 (MS2)

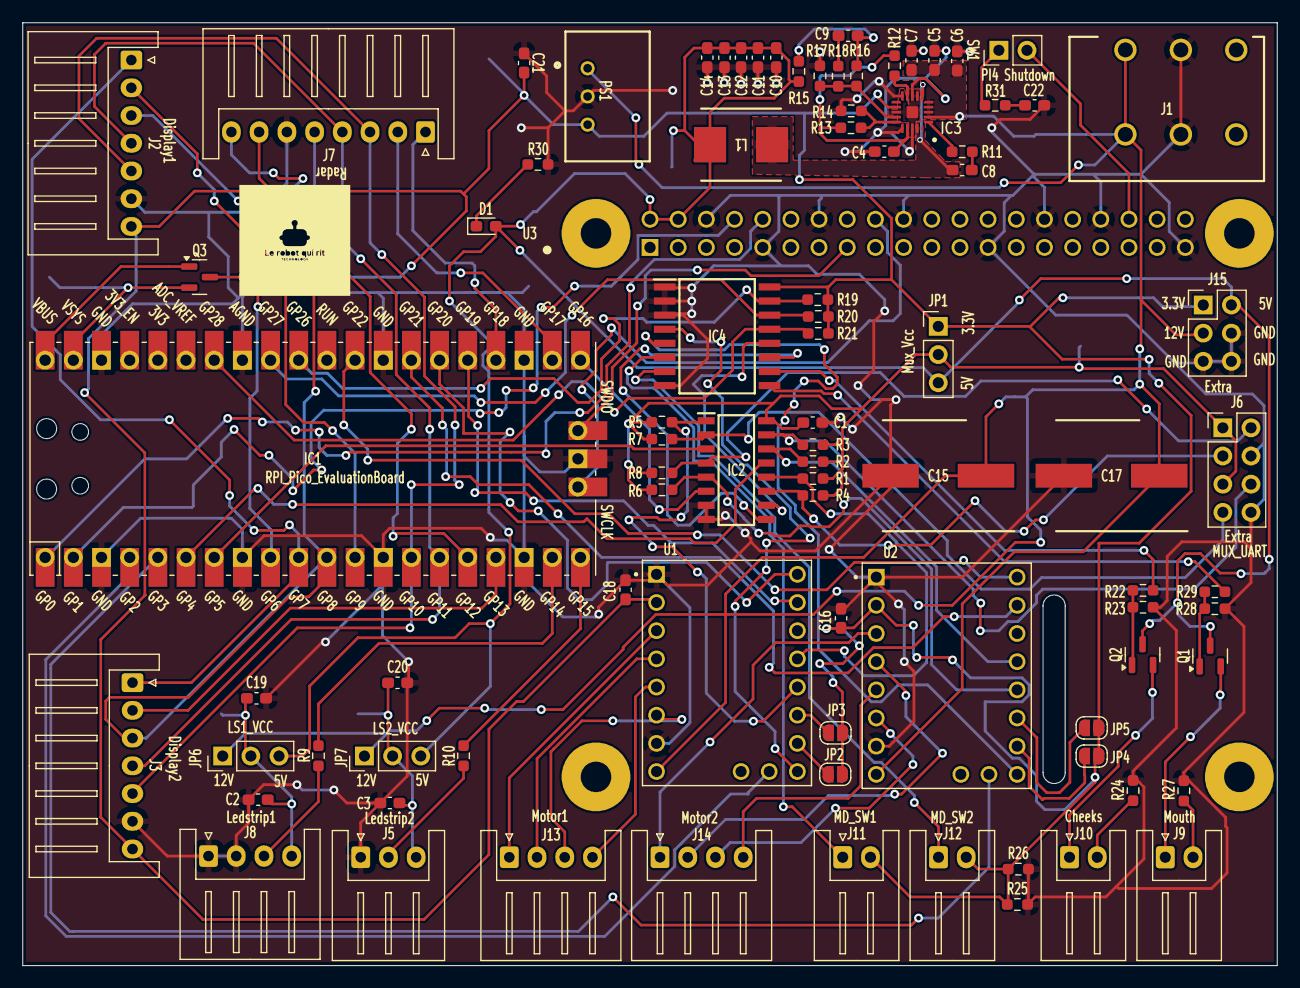
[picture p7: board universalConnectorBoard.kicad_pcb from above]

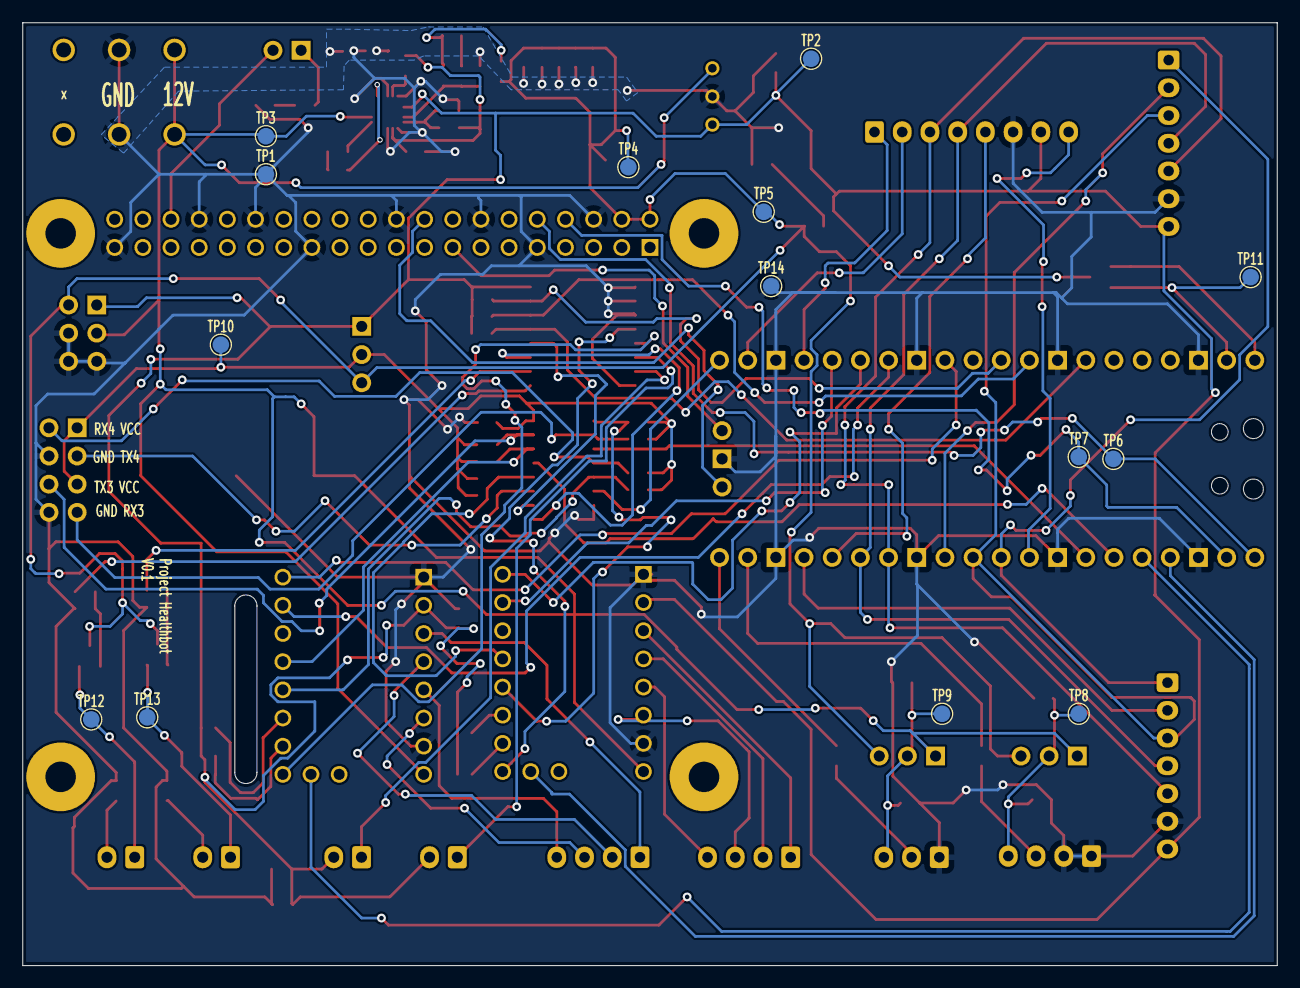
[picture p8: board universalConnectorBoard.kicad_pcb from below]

Board: 2 copper layers, 113.1 x 85.0 mm, 103 parts (14 on the bottom side), 86 nets.

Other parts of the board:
Logo: d0ed0aed-a5b7-4fbb-959d-d2596cb26e0d

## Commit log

2024-04-19 Add initial project folder structure, with seperate kicad project library.
    [universalConnectorBoard.kicad_pcb, universalConnectorBoard.kicad_sch]
2024-04-19 Added footprints
2024-04-20 Add pico board footprint with through-hole and smd in one, just found it and thought it is something for the PCB.
    [universalConnectorBoard.kicad_pcb, universalConnectorBoard.kicad_sch]
2024-04-24 Added several components and connections
    [universalConnectorBoard.kicad_sch]
2024-04-24 Added more components
    [universalConnectorBoard.kicad_sch]
2024-04-26 Multiple additions
    [universalConnectorBoard.kicad_pcb, universalConnectorBoard.kicad_sch]
2024-04-26 Added lots of connections
    [universalConnectorBoard.kicad_pcb, universalConnectorBoard.kicad_sch]
2024-05-08 All pico GPIO pins assigned
    [universalConnectorBoard.kicad_pcb, universalConnectorBoard.kicad_sch]
2024-05-08 Added excel sheet for overview of pin connections
    [universalConnectorBoard.kicad_pcb]
2024-05-08 Excel adjustion
    [Connections.xlsx]
2024-05-15 Added power management
    [PowerManagement.kicad_sch, universalConnectorBoard.kicad_pcb, universalConnectorBoard.kicad_sch]
2024-05-16 Schematic nearly done, ordened
    [Connections.xlsx, PowerManagement.kicad_sch, universalConnectorBoard.kicad_pcb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]
2024-05-16 Added new sheet for motors
    [StepperMotors.kicad_sch]
2024-05-17 Finished schematic, in review
    [PowerManagement.kicad_sch, StepperMotors.kicad_sch, universalConnectorBoard.kicad_pcb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]
2024-05-17 -add missing connections in schematic, and some other small changes
    [PowerManagement.kicad_sch, StepperMotors.kicad_sch, universalConnectorBoard.kicad_sch]
2024-05-22 Schematic finished
    [PowerManagement.kicad_sch, RPI4.kicad_sch, StepperMotors.kicad_sch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]
2024-05-22 Added Pi HAT reference footprint
    [RPI4.kicad_sch, universalConnectorBoard.kicad_pcb, universalConnectorBoard.kicad_sch]
2024-05-23 Added RPI4 footprint + headers, start of pcb designer
    [universalConnectorBoard.kicad_sch]
2024-05-24 All components placed
    [PowerManagement.kicad_sch, universalConnectorBoard.kicad_pcb, universalConnectorBoard.kicad_sch]
2024-05-24 Minor movements
    [universalConnectorBoard.kicad_pcb]
2024-05-24 PCB Design halfway
    [PowerManagement.kicad_sch, universalConnectorBoard.kicad_pcb]
2024-05-24 Nearly finished, just some DRC Errors te check
    [universalConnectorBoard.kicad_pcb, universalConnectorBoard.kicad_sch]
2024-05-24 Added name on PCB....
    [universalConnectorBoard.kicad_pcb]
2024-05-26 Added all neccessary files for ordering
    [PowerManagement.kicad_sch, StepperMotors.kicad_sch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]
2024-05-26 Added generated BOM file (as excel, csv did not commit
    [BOM.xlsx]
2024-05-26 Moved files folder
    [universalConnectorBoard-B_Cu.gbl, universalConnectorBoard-B_Mask.gbs, universalConnectorBoard-B_Paste.gbp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]
2024-05-29 Final version
    [Connections.xlsx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]
2024-06-05 Changed connections excel sheet
    [BOM.xlsx, Connections.xlsx]
2024-06-13 Added media
    [universalConnectorBoard.kicad_pcb]
